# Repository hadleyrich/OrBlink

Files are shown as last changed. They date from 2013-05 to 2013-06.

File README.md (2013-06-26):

OrBlink
=======
Copyright 2013 nice technology Ltd  
Website: <http://nicegear.co/orblink>

An open source USB controlled RGB LED designed to go inside a small
plastic orb. Allows you to control the LED to any color meaning
you can indicate whatever you can imagine from a computer or other
USB host device.

Features:

 * Acts as a human interface device (HID) meaning it doesn't
   need drivers on Linux, Mac or Windows.
 * Based on the Atmel ATTiny85 like many other similar projects so
   you can use the firmware of your choice.
 * Supplied with example code for multiple operating systems.

LICENSE
-------
The hardware design files are licensed under the TAPR Open Hardware License
(www.tapr.org/OHL). See the "hardware/LICENSE" file within this repository
for the full license in plain text format.

The software is licensed under various open source licenses, please see the
LICENSE file within each directory or header in the source code files.

INSTALLATION
------------
The design is saved as an EAGLE project. EAGLE PCB design software is
available from www.cadsoftusa.com free for non-commercial use. To use
this project download it and place the directory containing these files
into the "eagle" directory on your computer. Then open EAGLE and
navigate to Projects -> eagle -> OrBlink.

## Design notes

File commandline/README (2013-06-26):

Modified from code by Dave Hillier; https://code.google.com/p/avr-usb-rgb-led/

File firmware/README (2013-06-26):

Modified from code by Dave Hillier; https://code.google.com/p/avr-usb-rgb-led/

Originally based on some V-USB example code released under the GPL license.

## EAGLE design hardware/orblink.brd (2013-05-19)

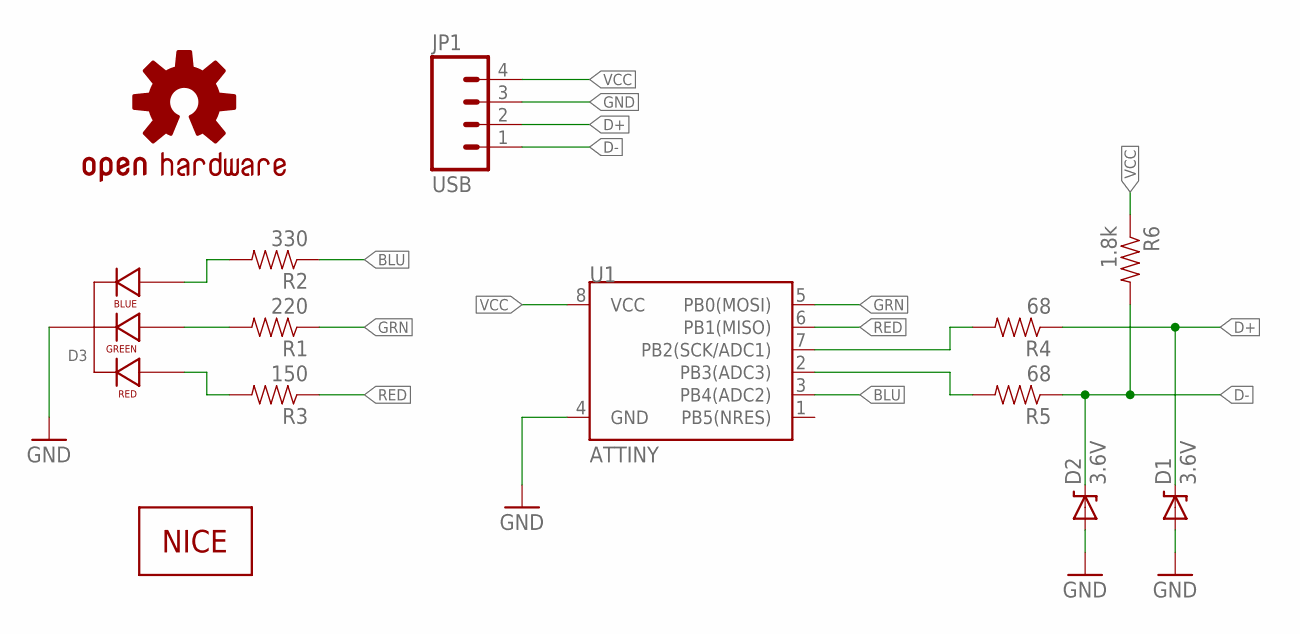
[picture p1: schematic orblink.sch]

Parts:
D1, D2: 3.6V; DIODE-ZENER
D3: LED-RGB-CC-THRUDIFFUSE; LED-RGB-THRU
JP1: USB; 1X04
LOGO1: OSHW-LOGOS; OSHW-LOGO-S
R1: 220; 1/6W-RES
R2: 330; 1/6W-RES
R3: 150; 1/6W-RES
R4, R5: 68; 1/6W-RES
R6: 1.8k; 1/6W-RES
U1: ATTINY; DIP08
U$1: NICE-LOGO04; NICE-LOGO-04

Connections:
BLU: R2.1, U1.3 (PB4(ADC2))
D+: D1.P$1 (C), JP1.2, R4.1
D-: D2.P$1 (C), JP1.1, R5.1, R6.2
GND: D1.P$2 (A), D2.P$2 (A), D3.2 (CATHODE), JP1.3, U1.4 (GND)
GRN: R1.1, U1.5 (PB0(MOSI))
unnamed: D3.4 (BLUE_CATHODE), R2.2
unnamed: D3.3 (GREEN_CATHODE), R1.2
unnamed: R4.2, U1.7 (PB2(SCK/ADC1))
unnamed: R5.2, U1.2 (PB3(ADC3))
unnamed: D3.1 (RED_CATHODE), R3.2
RED: R3.1, U1.6 (PB1(MISO))
VCC: JP1.4, R6.1, U1.8 (VCC)

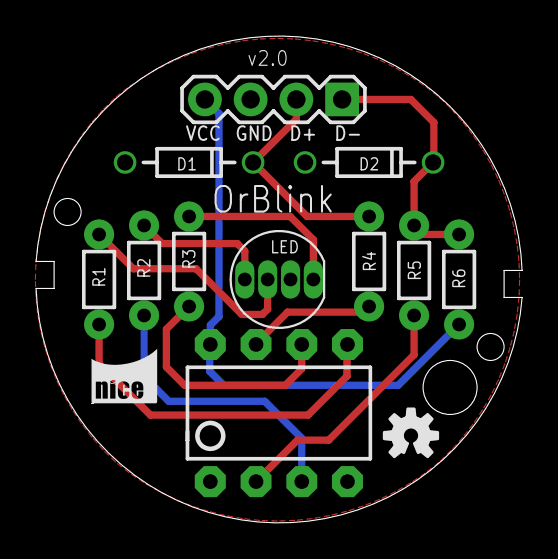
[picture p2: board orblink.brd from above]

Board: 2 copper layers, 27.0 x 27.0 mm, 13 parts (0 on the bottom side), 12 nets.

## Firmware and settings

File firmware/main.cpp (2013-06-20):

/* Name: main.c
 * Project: hid-custom-rq example
 * Author: Christian Starkjohann
 * Creation Date: 2008-04-07
 * Tabsize: 4
 * Copyright: (c) 2008 by OBJECTIVE DEVELOPMENT Software GmbH
 * License: GNU GPL v2 (see License.txt), GNU GPL v3 or proprietary (CommercialLicense.txt)
 * This Revision: $Id: main.c 692 2008-11-07 15:07:40Z cs $
 */

/*
This example should run on most AVRs with only little changes. No special
hardware resources except INT0 are used. You may have to change usbconfig.h for
different I/O pins for USB. Please note that USB D+ must be the INT0 pin, or
at least be connected to INT0 as well.
We assume that an LED is connected to port B bit 0. If you connect it to a
different port or bit, change the macros below:
*/
#define LED_PORT_DDR        DDRB
#define LED_PORT_OUTPUT     PORTB
#define R_BIT            1
#define G_BIT            0
#define B_BIT            4


#include <avr/io.h>
#include <avr/wdt.h>
#include <avr/eeprom.h>
#include <avr/interrupt.h>  /* for sei() */
#include <util/delay.h>     /* for _delay_ms() */

#include <avr/pgmspace.h>   /* required by usbdrv.h */
extern "C"
{
	#include "usbdrv.h"
}
#include "oddebug.h"        /* This is also an example for using debug macros */
#include "requests.h"       /* The custom request numbers we use */

/* ------------------------------------------------------------------------- */
/* ----------------------------- USB interface ----------------------------- */
/* ------------------------------------------------------------------------- */

PROGMEM const char usbHidReportDescriptor[22] = {    /* USB report descriptor */
    0x06, 0x00, 0xff,              // USAGE_PAGE (Generic Desktop)
    0x09, 0x01,                    // USAGE (Vendor Usage 1)
    0xa1, 0x01,                    // COLLECTION (Application)
    0x15, 0x00,                    //   LOGICAL_MINIMUM (0)
    0x26, 0xff, 0x00,              //   LOGICAL_MAXIMUM (255)
    0x75, 0x08,                    //   REPORT_SIZE (8)
    0x95, 0x01,                    //   REPORT_COUNT (1)
    0x09, 0x00,                    //   USAGE (Undefined)
    0xb2, 0x02, 0x01,              //   FEATURE (Data,Var,Abs,Buf)
    0xc0                           // END_COLLECTION
};
/* The descriptor above is a dummy only, it silences the drivers. The report
 * it describes consists of one byte of undefined data.
 * We don't transfer our data through HID reports, we use custom requests
 * instead.
 */
static uint8_t count = 0;
static volatile uint8_t r = 0;
static volatile uint8_t g = 0;
static volatile uint8_t b = 0;
static uint8_t rb = 0;
static uint8_t gb = 0;
static uint8_t bb = 0;

/* ------------------------------------------------------------------------- */

extern "C" usbMsgLen_t usbFunctionSetup(uchar data[8])
{
	usbRequest_t    *rq = (usbRequest_t *)data;

    if((rq->bmRequestType & USBRQ_TYPE_MASK) == USBRQ_TYPE_VENDOR)
	{
		switch(rq->bRequest)
		{
		case CUSTOM_RQ_SET_RED:
			r = rq->wValue.bytes[0];
			break;	
		case CUSTOM_RQ_SET_GREEN:
			g = rq->wValue.bytes[0];
			break;	
		case CUSTOM_RQ_SET_BLUE:
			b = rq->wValue.bytes[0];
			break;	
		}
    }
	else
	{
        /* class requests USBRQ_HID_GET_REPORT and USBRQ_HID_SET_REPORT are
         * not implemented since we never call them. The operating system
         * won't call them either because our descriptor defines no meaning.
         */
    }
    return 0;   /* default for not implemented requests: return no data back to host */
}

static void calibrateOscillator(void)
{
uchar       step = 128;
uchar       trialValue = 0, optimumValue;
int         x, optimumDev, targetValue = (unsigned)(1499 * (double)F_CPU / 10.5e6 + 0.5);
 
    /* do a binary search: */
    do{
        OSCCAL = trialValue + step;
        x = usbMeasureFrameLength();    // proportional to current real frequency
        if(x < targetValue)             // frequency still too low
            trialValue += step;
        step >>= 1;
    }while(step > 0);
    /* We have a precision of +/- 1 for optimum OSCCAL here */
    /* now do a neighborhood search for optimum value */
    optimumValue = trialValue;
    optimumDev = x; // this is certainly far away from optimum
    for(OSCCAL = trialValue - 1; OSCCAL <= trialValue + 1; OSCCAL++){
        x = usbMeasureFrameLength() - targetValue;
        if(x < 0)
            x = -x;
        if(x < optimumDev){
            optimumDev = x;
            optimumValue = OSCCAL;
        }
    }
    OSCCAL = optimumValue;
}
 

extern "C" void usbEventResetReady(void)
{
    cli();  // usbMeasureFrameLength() counts CPU cycles, so disable interrupts.
    calibrateOscillator();
    sei();
    eeprom_write_byte(0, OSCCAL);   // store the calibrated value in EEPROM
}

/* ------------------------------------------------------------------------- */
void update_leds()
{
  if (++count == 0) {    
    rb = r;
    gb = g;
    bb = b;
    // check if switch on r, g and b
    if (rb > 0) {        
      PORTB |= (1 << R_BIT);
    } 
    if (gb > 0) {
      PORTB |= (1 << G_BIT);
    } 
    if (bb > 0) {
      PORTB |= (1 << B_BIT);
    } 
  }
  // check if switch off r, g and b
  if (count == rb) {     
    PORTB &= ~(1 << R_BIT);
  }
  if (count == gb) {
    PORTB &= ~(1 << G_BIT);
  }
  if (count == bb) {
    PORTB &= ~(1 << B_BIT);
  }
}

void update_leds2()
{
    /* PWM enable,  */
    GTCCR |= _BV(PWM1B) | _BV(COM1B1);

    TCCR0A |= _BV(WGM00) | _BV(WGM01) | _BV(COM0A1) | _BV(COM0B1);

    /* Start timer 0 and 1 */
    TCCR1 |= _BV(CS10);

    TCCR0B |=  _BV(CS00);

    /* Set PWM value to 0. */
    OCR0A = 255;   // PB0
    OCR0B = 255;   // PB1
    OCR1B = 255;   // PB4
}

int main(void)
{
	uchar   i;

    wdt_enable(WDTO_1S);
    /* Even if you don't use the watchdog, turn it off here. On newer devices,
     * the status of the watchdog (on/off, period) is PRESERVED OVER RESET!
     */
    /* RESET status: all port bits are inputs without pull-up.
     * That's the way we need D+ and D-. Therefore we don't need any
     * additional hardware initialization.
     */

    usbInit();
    usbDeviceDisconnect();  /* enforce re-enumeration, do this while interrupts are disabled! */
    i = 0;
    while(--i){             /* fake USB disconnect for > 250 ms */
        wdt_reset();
        _delay_ms(1);
    }
    usbDeviceConnect();
    LED_PORT_DDR |= _BV(R_BIT);   /* make the LED bit an output */
    LED_PORT_DDR |= _BV(G_BIT);   /* make the LED bit an output */
    LED_PORT_DDR |= _BV(B_BIT);   /* make the LED bit an output */
	
    sei();

    for(;;){                /* main event loop */
		update_leds();
		
        wdt_reset();
        usbPoll();
    }
    return 0;
}

/* ------------------------------------------------------------------------- */

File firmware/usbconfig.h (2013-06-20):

/* Name: usbconfig.h
 * Project: AVR USB driver
 * Author: Christian Starkjohann
 * Creation Date: 2005-04-01
 * Tabsize: 4
 * Copyright: (c) 2005 by OBJECTIVE DEVELOPMENT Software GmbH
 * License: GNU GPL v2 (see License.txt), GNU GPL v3 or proprietary (CommercialLicense.txt)
 * This Revision: $Id: usbconfig-prototype.h 692 2008-11-07 15:07:40Z cs $
 */

#ifndef __usbconfig_h_included__
#define __usbconfig_h_included__


#ifndef __ASSEMBLER__
extern void usbEventResetReady(void);
#endif
#define USB_RESET_HOOK(isReset)         if(!isReset){usbEventResetReady();}

/*
General Description:
This file is an example configuration (with inline documentation) for the USB
driver. It configures AVR-USB for USB D+ connected to Port D bit 2 (which is
also hardware interrupt 0 on many devices) and USB D- to Port D bit 4. You may
wire the lines to any other port, as long as D+ is also wired to INT0 (or any
other hardware interrupt, as long as it is the highest level interrupt, see
section at the end of this file).
*/

/* ---------------------------- Hardware Config ---------------------------- */

#define USB_CFG_IOPORTNAME      B
/* This is the port where the USB bus is connected. When you configure it to
 * "B", the registers PORTB, PINB and DDRB will be used.
 */
#define USB_CFG_DMINUS_BIT      3
/* This is the bit number in USB_CFG_IOPORT where the USB D- line is connected.
 * This may be any bit in the port.
 */
#define USB_CFG_DPLUS_BIT       2
/* This is the bit number in USB_CFG_IOPORT where the USB D+ line is connected.
 * This may be any bit in the port. Please note that D+ must also be connected
 * to interrupt pin INT0! [You can also use other interrupts, see section
 * "Optional MCU Description" below, or you can connect D- to the interrupt, as
 * it is required if you use the USB_COUNT_SOF feature. If you use D- for the
 * interrupt, the USB interrupt will also be triggered at Start-Of-Frame
 * markers every millisecond.]
 */
#define USB_CFG_CLOCK_KHZ       (F_CPU/1000)
/* Clock rate of the AVR in MHz. Legal values are 12000, 12800, 15000, 16000,
 * 16500 and 20000. The 12.8 MHz and 16.5 MHz versions of the code require no
 * crystal, they tolerate +/- 1% deviation from the nominal frequency. All
 * other rates require a precision of 2000 ppm and thus a crystal!
 * Default if not specified: 12 MHz
 */

/* ----------------------- Optional Hardware Config ------------------------ */

/* #define USB_CFG_PULLUP_IOPORTNAME   D */
/* If you connect the 1.5k pullup resistor from D- to a port pin instead of
 * V+, you can connect and disconnect the device from firmware by calling
 * the macros usbDeviceConnect() and usbDeviceDisconnect() (see usbdrv.h).
 * This constant defines the port on which the pullup resistor is connected.
 */
/* #define USB_CFG_PULLUP_BIT          4 */
/* This constant defines the bit number in USB_CFG_PULLUP_IOPORT (defined
 * above) where the 1.5k pullup resistor is connected. See description
 * above for details.
 */

/* --------------------------- Functional Range ---------------------------- */
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

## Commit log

2013-05-19 Switched LED and USB pin
    [orblink.brd, orblink.sch]
2013-06-20 Move hardware design files and python code to subdirectories
    [orblink.brd, orblink.sch]
2014-01-13 expand commandline not found message to also mention that device not found can be casued be lack of permissions as well
2014-01-13 add sample udev rules file for making the device file accessiable to non root users under Linux

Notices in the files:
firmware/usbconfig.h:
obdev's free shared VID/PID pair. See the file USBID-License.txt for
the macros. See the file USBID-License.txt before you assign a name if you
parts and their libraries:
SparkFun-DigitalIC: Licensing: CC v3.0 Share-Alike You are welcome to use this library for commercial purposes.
